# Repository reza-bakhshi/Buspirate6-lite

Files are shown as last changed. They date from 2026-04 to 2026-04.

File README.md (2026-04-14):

# ⚠️ THIS PROJECT IS UNDER ACTIVE DEVELOPMENT AND TESTING  

## DO NOT MANUFACTURE OR USE THE HARDWARE WITHOUT YOUR OWN VERIFICATION

## Overview

This project is currently in progress. Features, hardware design, and functionality may change at any time. Use at your own risk.

---

## Images

### TOP

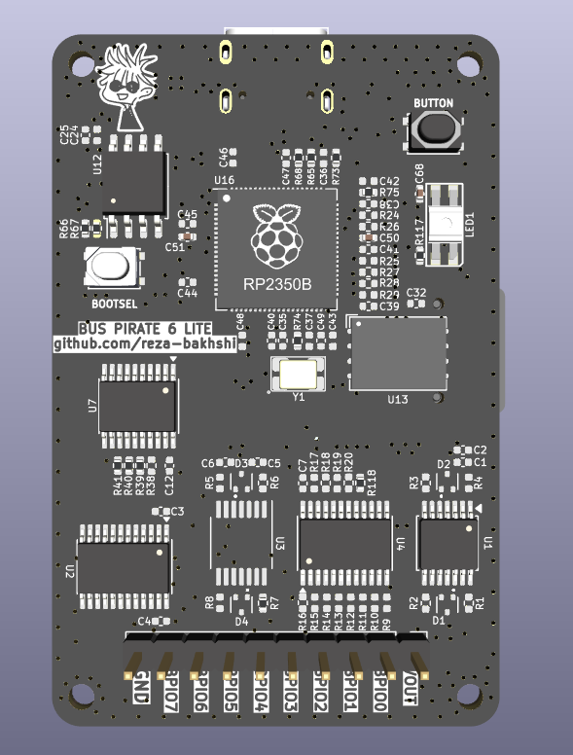
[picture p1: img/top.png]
top


### BOTTOM

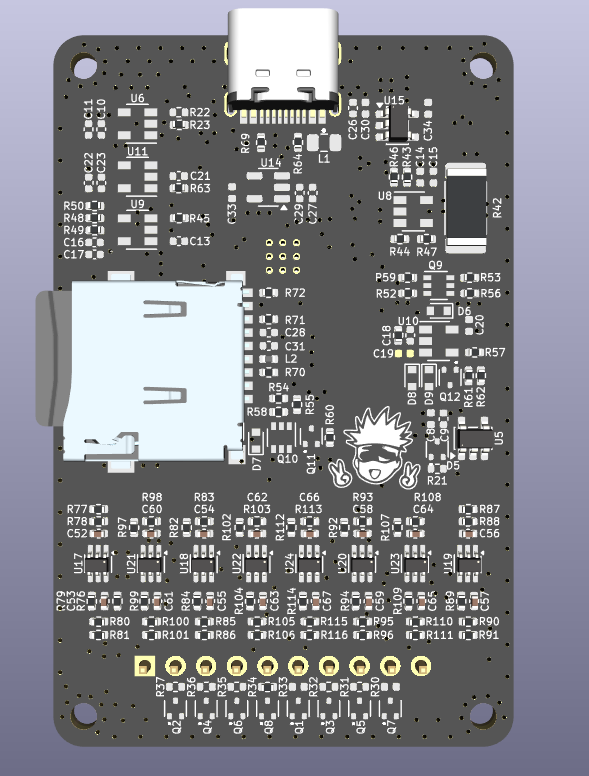
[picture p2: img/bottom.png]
bottom


---

## Notes

- This project is not stable yet.
- Hardware and firmware are still being tested.
- Double-check everything before using or manufacturing.

---

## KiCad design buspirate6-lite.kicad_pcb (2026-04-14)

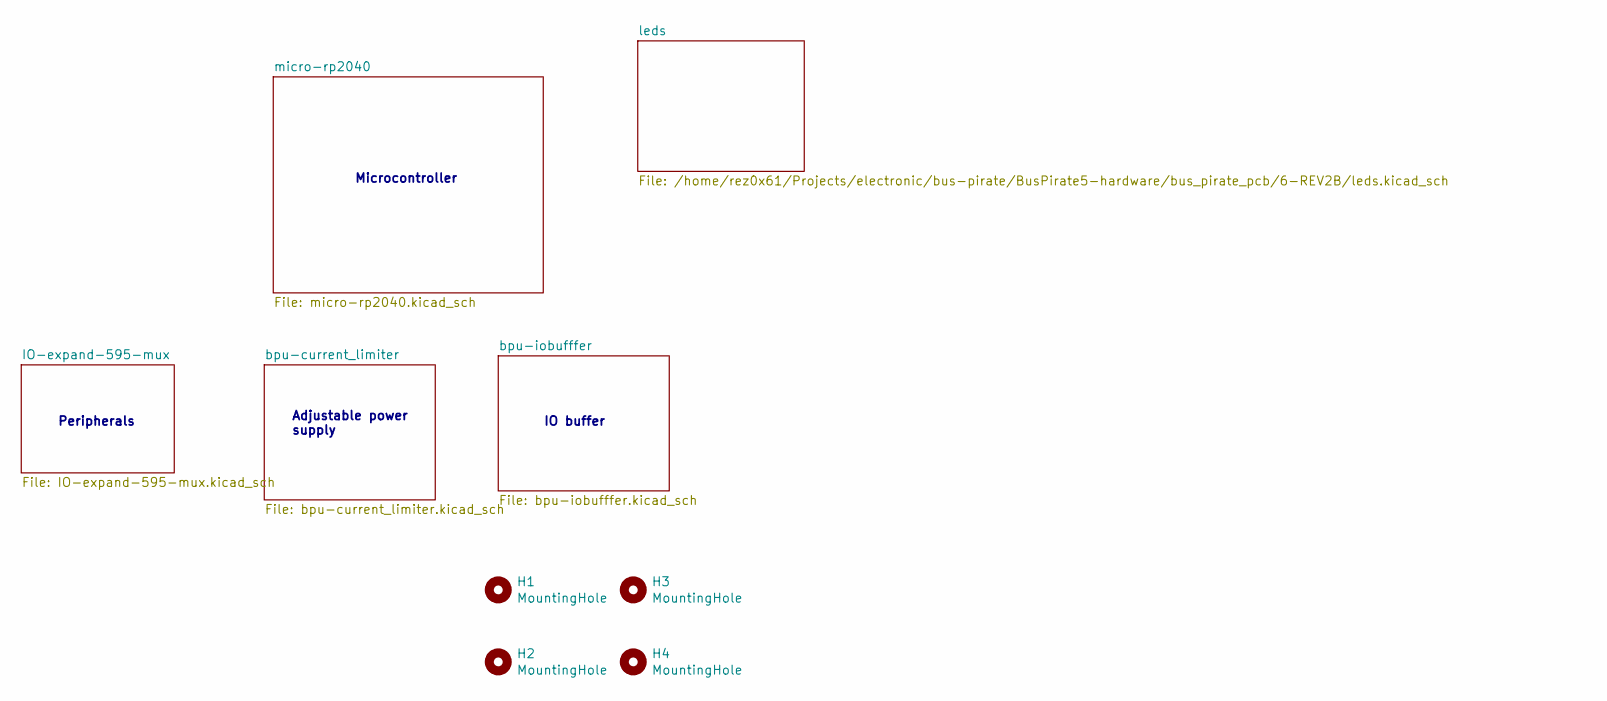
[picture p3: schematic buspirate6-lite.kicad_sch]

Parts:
H1, H2, H3, H4: MountingHole; MountingHole_2.2mm_M2

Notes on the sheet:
Microcontroller
Adjustable power supply
IO buffer
Peripherals

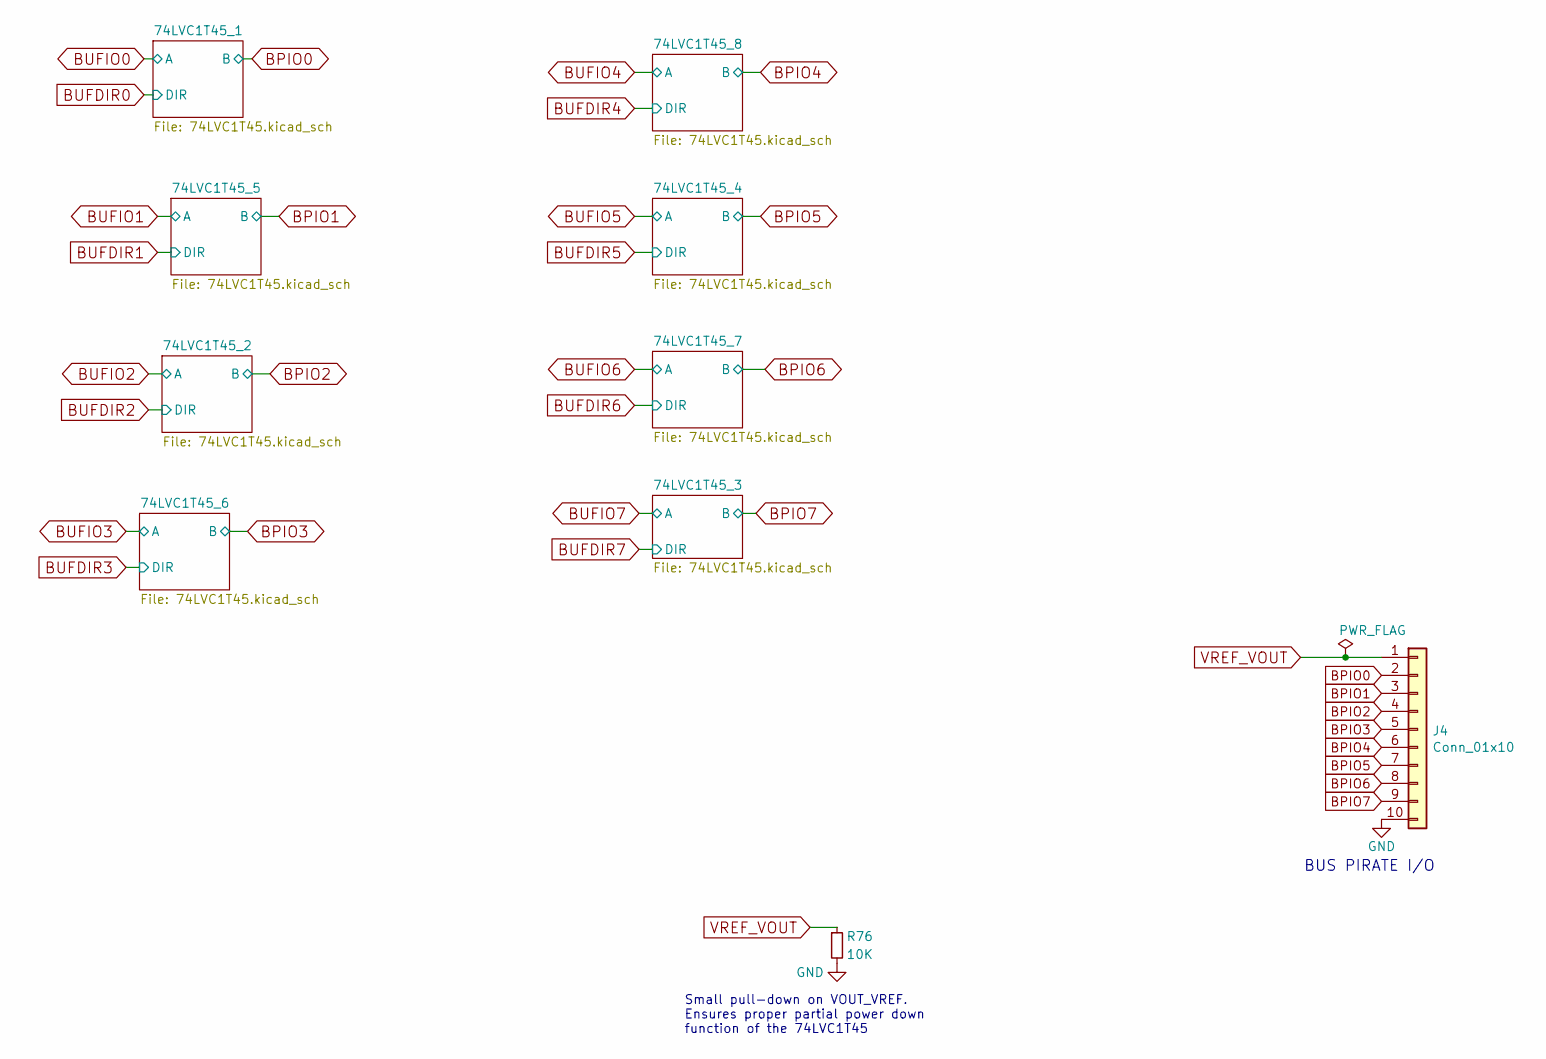
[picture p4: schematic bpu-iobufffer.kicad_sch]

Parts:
J4: Conn_01x10; PinHeader_1x10_P2.54mm_Vertical
R76: 10K; R_0402_1005Metric

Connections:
BPIO0: J4.2; also elsewhere on the board
BPIO1: J4.3; also elsewhere on the board
BPIO2: J4.4; also elsewhere on the board
BPIO3: J4.5; also elsewhere on the board
BPIO4: J4.6; also elsewhere on the board
BPIO5: J4.7; also elsewhere on the board
BPIO6: J4.8; also elsewhere on the board
BPIO7: J4.9; also elsewhere on the board
GND: J4.10, R76.2; also elsewhere on the board
VREF_VOUT: J4.1, R76.1; also elsewhere on the board

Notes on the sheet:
Small pull-down on VOUT_VREF. Ensures proper partial power down function of the 74LVC1T45
BUS PIRATE I/O

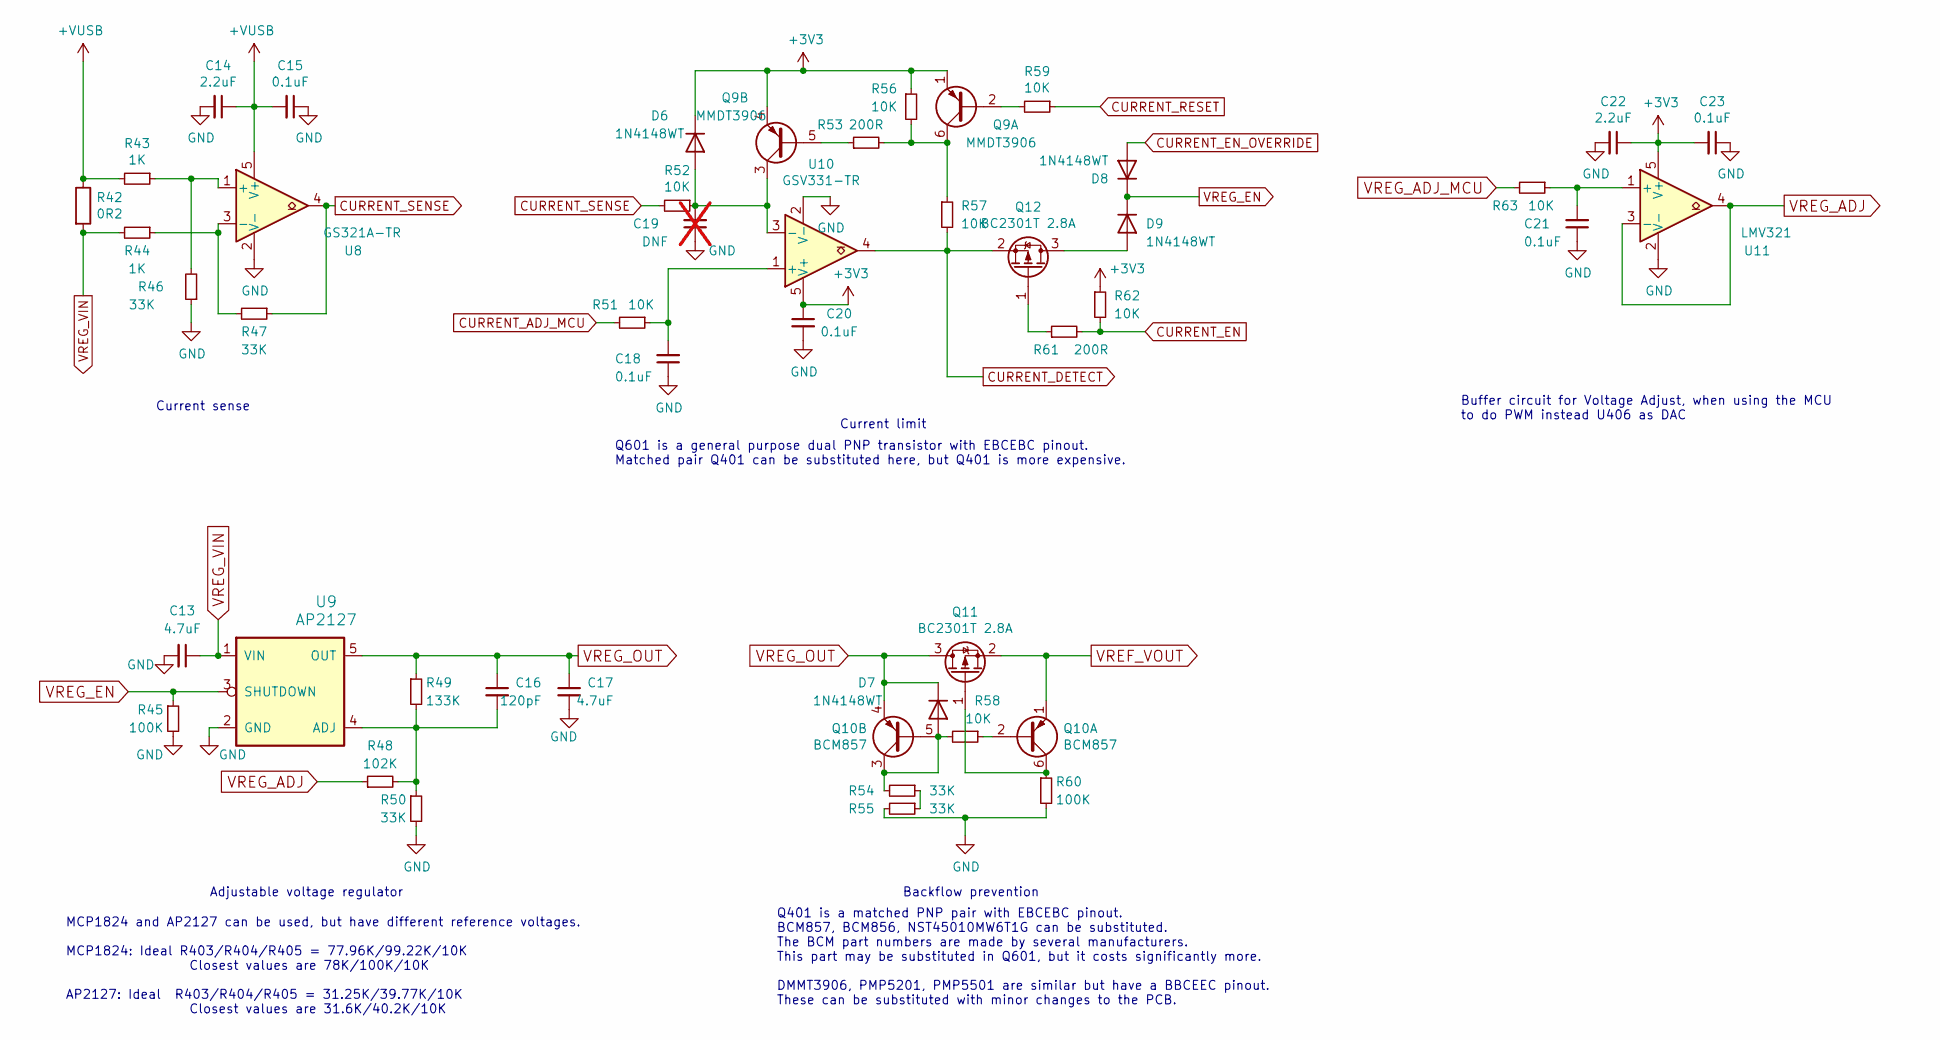
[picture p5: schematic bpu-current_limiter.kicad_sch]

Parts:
C13, C17: 4.7uF; C_0402_1005Metric
C14, C22: 2.2uF; C_0402_1005Metric
C15, C18, C20, C21, C23: 0.1uF; C_0402_1005Metric
C16: 120pF; C_0402_1005Metric
C19: DNF; C_0402_1005Metric; not fitted
D6, D7, D8, D9: 1N4148WT; D_SOD-523
Q9: MMDT3906; SOT-363_SC-70-6
Q10: BCM857; SOT-363_SC-70-6
Q11, Q12: BC2301T 2.8A; SOT-523
R42: 0R2; R_2512_6332Metric_Pad1.40x3.35mm_HandSolder
R43, R44: 1K; R_0402_1005Metric
R45, R60: 100K; R_0402_1005Metric
R46, R47, R50, R54, R55: 33K; R_0402_1005Metric
R48: 102K; R_0402_1005Metric
R49: 133K; R_0402_1005Metric
R51, R52, R56, R57, R58, R59, R62, R63: 10K; R_0402_1005Metric
R53, R61: 200R; R_0402_1005Metric
U8: GS321A-TR; SOT-23-5
U9: AP2127; SOT-23-5
U10: GSV331-TR; SOT-23-5
U11: LMV321; SOT-23-5

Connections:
+3V3: C20.1, C22.1, C23.2, D6.1 (K), Q9.1 (E1), Q9.4 (E2), R56.1, R62.1, U10.5 (V+), U11.5 (V+); also elsewhere on the board
+VUSB: C14.1, C15.2, R42.1, R43.2, U8.5 (V+); also elsewhere on the board
CURRENT_ADJ_MCU: R51.2; also elsewhere on the board
CURRENT_DETECT: Q12.2 (S), R57.2, U10.4; also elsewhere on the board
CURRENT_EN: R61.2, R62.2; also elsewhere on the board
CURRENT_EN_OVERRIDE: D8.2 (A); also elsewhere on the board
CURRENT_RESET: R59.1; also elsewhere on the board
CURRENT_SENSE: R47.1, R52.2, U8.4; also elsewhere on the board
GND: C13.2, C14.2, C15.1, C17.2, C18.1, C19.1, C20.2, C21.1, C22.2, C23.1, R45.2, R46.1, R50.2, R55.2, R60.2, U8.2 (V-), U9.2 (GND), U10.2 (V-), U11.2 (V-); also elsewhere on the board
unnamed: C19.2, D6.2 (A), Q9.3 (C2), R52.1, U10.3 (-)
unnamed: D7.2 (A), Q10.3 (C2), Q10.5 (B2), R54.2, R58.2
unnamed: D9.2 (A), Q12.3 (D)
unnamed: Q9.2 (B1), R59.2
unnamed: Q9.6 (C1), R53.2, R56.2, R57.1
unnamed: Q9.5 (B2), R53.1
unnamed: Q10.2 (B1), R58.1
unnamed: Q10.6 (C1), Q11.1 (G), R60.1
unnamed: Q12.1 (G), R61.1
unnamed: R54.1, R55.1
unnamed: R43.1, R46.2, U8.1 (+)
unnamed: R44.1, R47.2, U8.3 (-)
unnamed: C16.2, R48.2, R49.2, R50.1, U9.4 (ADJ)
unnamed: C18.2, R51.1, U10.1 (+)
unnamed: C21.2, R63.1, U11.1 (+)
VREF_VOUT: Q10.1 (E1), Q11.2 (S); also elsewhere on the board
VREG_ADJ: R48.1, U11.3 (-), U11.4
VREG_ADJ_MCU: R63.2; also elsewhere on the board
VREG_EN: D8.1 (K), D9.1 (K), R45.1, U9.3 (SHUTDOWN)
VREG_OUT: C16.1, C17.1, D7.1 (K), Q10.4 (E2), Q11.3 (D), R49.1, U9.5 (OUT); also elsewhere on the board
VREG_VIN: C13.1, R42.2, R44.2, U9.1 (VIN)

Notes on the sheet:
Adjustable voltage regulator
Buffer circuit for Voltage Adjust, when using the MCU to do PWM instead U406 as DAC
Current sense
Backflow prevention
MCP1824 and AP2127 can be used, but have different reference voltages. MCP1824: Ideal R403/R404/R405 = 77.96K/99.22K/10K Closest values are 78K/100K/10K AP2127: Ideal R403/R404/R405 = 31.25K/39.77K/10K Closest values are 31.6K/40.2K/10K
Current limit
Q401 is a matched PNP pair with EBCEBC pinout. BCM857, BCM856, NST45010MW6T1G can be substituted. The BCM part numbers are made by several manufacturers. This part may be substituted in Q601, but it costs significantly more. DMMT3906, PMP5201, PMP5501 are similar but have a BBCEEC pinout. These can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
Q601 is a general purpose dual PNP transistor with EBCEBC pinout. Matched pair Q401 can be substituted here, but Q401 is more expensive.

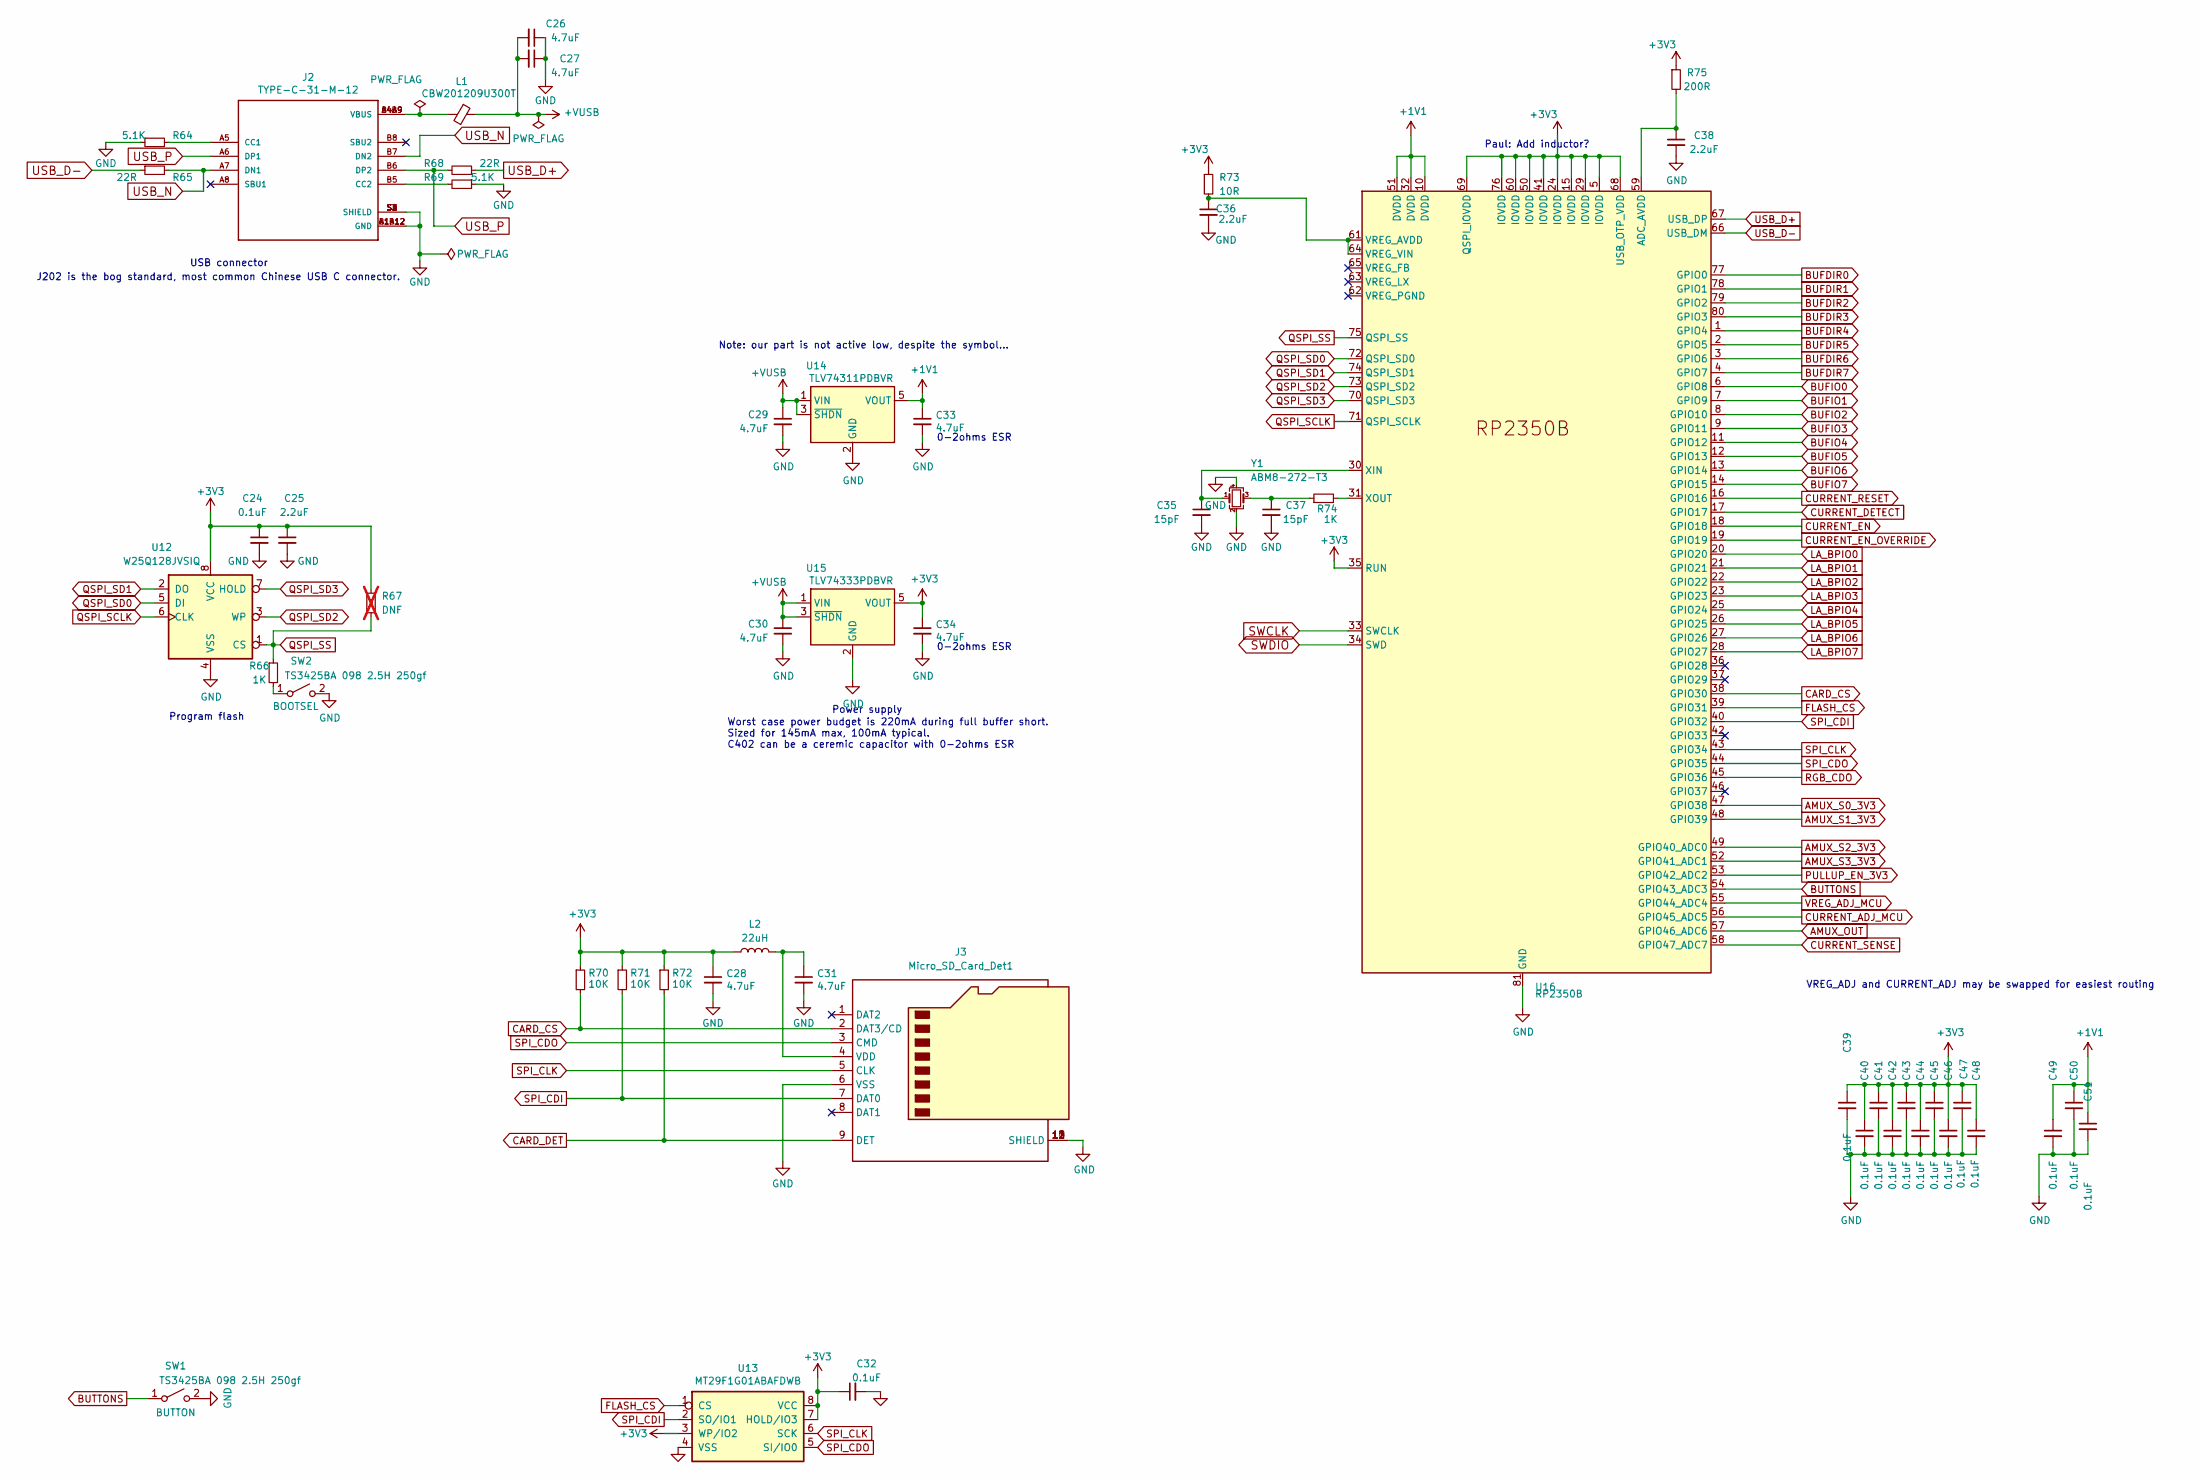
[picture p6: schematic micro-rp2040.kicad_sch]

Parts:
C24, C32, C39, C40, C41, C42, C43, C44, C45, C46, C47, C48, C49, C50, C51: 0.1uF; C_0402_1005Metric
C25, C36, C38: 2.2uF; C_0402_1005Metric
C26, C27, C28, C29, C30, C31, C33, C34: 4.7uF; C_0402_1005Metric
C35, C37: 15pF; C_0402_1005Metric
J2: TYPE-C-31-M-12; HRO_TYPE-C-31-M-12
J3: Micro_SD_Card_Det1; microSD_External_Pin
L1: CBW201209U300T; L_0805_2012Metric
L2: 22uH; L_0402_1005Metric
R64, R69: 5.1K; R_0402_1005Metric
R65, R68: 22R; R_0402_1005Metric
R66, R74: 1K; R_0402_1005Metric
R67: DNF; R_0402_1005Metric; not fitted
R70, R71, R72: 10K; R_0402_1005Metric
R73: 10R; R_0402_1005Metric
R75: 200R; R_0402_1005Metric
SW1, SW2: TS3425BA 098 2.5H 250gf; SW_SPST_PTS810
U12: W25Q128JVSIQ; SOP-8_5.28x5.23mm_P1.27mm
U13: MT29F1G01ABAFDWB; U-PDFN-8
U14: TLV74311PDBVR; SOT-23-5
U15: TLV74333PDBVR; SOT-23-5
U16: RP2350B; qfn80
Y1: ABM8-272-T3; Crystal_SMD_4Pin

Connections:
+1V1: C33.1, C49.1, C50.1, C51.1, U14.5 (VOUT), U16.10 (DVDD), U16.32 (DVDD), U16.51 (DVDD)
+3V3: C24.1, C25.1, C28.1, C32.1, C34.1, C39.1, C40.1, C41.1, C42.1, C43.1, C44.1, C45.1, C46.1, C47.1, C48.1, L2.1, R67.1, R70.1, R71.1, R72.1, R73.1, R75.1, U12.8 (VCC), U13.3 (WP/IO2), U13.7 (HOLD/IO3), U13.8 (VCC), U15.5 (VOUT), U16.5 (IOVDD), U16.15 (IOVDD), U16.24 (IOVDD), U16.29 (IOVDD), U16.35 (RUN), U16.41 (IOVDD), U16.50 (IOVDD), U16.60 (IOVDD), U16.68 (USB_OTP_VDD), U16.69 (QSPI_IOVDD), U16.76 (IOVDD); also elsewhere on the board
+VUSB: C26.2, C27.2, C29.1, C30.1, L1.1, U14.1 (VIN), U14.3 (~SHDN), U15.1 (VIN), U15.3 (~SHDN); also elsewhere on the board
AMUX_OUT: U16.57 (GPIO46_ADC6); also elsewhere on the board
AMUX_S0_3V3: U16.47 (GPIO38); also elsewhere on the board
AMUX_S1_3V3: U16.48 (GPIO39); also elsewhere on the board
AMUX_S2_3V3: U16.49 (GPIO40_ADC0); also elsewhere on the board
AMUX_S3_3V3: U16.52 (GPIO41_ADC1); also elsewhere on the board
BUFDIR0: U16.77 (GPIO0); also elsewhere on the board
BUFDIR1: U16.78 (GPIO1); also elsewhere on the board
BUFDIR2: U16.79 (GPIO2); also elsewhere on the board
BUFDIR3: U16.80 (GPIO3); also elsewhere on the board
BUFDIR4: U16.1 (GPIO4); also elsewhere on the board
BUFDIR5: U16.2 (GPIO5); also elsewhere on the board
BUFDIR6: U16.3 (GPIO6); also elsewhere on the board
BUFDIR7: U16.4 (GPIO7); also elsewhere on the board
BUFIO0: U16.6 (GPIO8); also elsewhere on the board
BUFIO1: U16.7 (GPIO9); also elsewhere on the board
BUFIO2: U16.8 (GPIO10); also elsewhere on the board
BUFIO3: U16.9 (GPIO11); also elsewhere on the board
BUFIO4: U16.11 (GPIO12); also elsewhere on the board
BUFIO5: U16.12 (GPIO13); also elsewhere on the board
BUFIO6: U16.13 (GPIO14); also elsewhere on the board
BUFIO7: U16.14 (GPIO15); also elsewhere on the board
BUTTONS: SW1.1 (A), U16.54 (GPIO43_ADC3)
CARD_CS: J3.2 (DAT3/CD), R70.2, U16.38 (GPIO30)
CARD_DET: J3.9 (DET), R72.2; also elsewhere on the board
CURRENT_ADJ_MCU: U16.56 (GPIO45_ADC5); also elsewhere on the board
CURRENT_DETECT: U16.17 (GPIO17); also elsewhere on the board
CURRENT_EN: U16.18 (GPIO18); also elsewhere on the board
CURRENT_EN_OVERRIDE: U16.19 (GPIO19); also elsewhere on the board
CURRENT_RESET: U16.16 (GPIO16); also elsewhere on the board
CURRENT_SENSE: U16.58 (GPIO47_ADC7); also elsewhere on the board
FLASH_CS: U13.1 (CS), U16.39 (GPIO31)
GND: C24.2, C25.2, C26.1, C27.1, C28.2, C29.2, C30.2, C31.2, C32.2, C33.2, C34.2, C35.2, C36.2, C37.2, C38.2, C39.2, C40.2, C41.2, C42.2, C43.2, C44.2, C45.2, C46.2, C47.2, C48.2, C49.2, C50.2, C51.2, J2.A1B12 (GND), J2.B1A12 (GND), J2.S1 (SHIELD), J2.S2 (SHIELD), J2.S3 (SHIELD), J2.S4 (SHIELD), J3.6 (VSS), J3.10 (SHIELD), J3.11 (SHIELD), J3.12 (SHIELD), J3.13 (SHIELD), R64.1, R69.1, SW1.2 (B), SW2.2 (B), U12.4 (VSS), U13.4 (VSS), U14.2 (GND), U14.4 (GND), U15.2 (GND), U15.4 (GND), U16.81 (GND), Y1.2, Y1.4; also elsewhere on the board
LA_BPIO0: U16.20 (GPIO20); also elsewhere on the board
LA_BPIO1: U16.21 (GPIO21); also elsewhere on the board
LA_BPIO2: U16.22 (GPIO22); also elsewhere on the board
LA_BPIO3: U16.23 (GPIO23); also elsewhere on the board
LA_BPIO4: U16.25 (GPIO24); also elsewhere on the board
LA_BPIO5: U16.26 (GPIO25); also elsewhere on the board
LA_BPIO6: U16.27 (GPIO26); also elsewhere on the board
LA_BPIO7: U16.28 (GPIO27); also elsewhere on the board
unnamed: C37.1, R74.1, Y1.3
unnamed: J2.A5 (CC1), R64.2
unnamed: J2.B5 (CC2), R69.2
unnamed: J2.A4B9 (VBUS), J2.B4A9 (VBUS), L1.2
unnamed: C31.1, J3.4 (VDD), L2.2
unnamed: R66.2, SW2.1 (A)
unnamed: C38.1, R75.2, U16.59 (ADC_AVDD)
unnamed: C36.1, R73.2, U16.61 (VREG_AVDD), U16.64 (VREG_VIN)
unnamed: C35.1, U16.30 (XIN), Y1.1
unnamed: R74.2, U16.31 (XOUT)
PULLUP_EN_3V3: U16.53 (GPIO42_ADC2); also elsewhere on the board
QSPI_SCLK: U12.6 (CLK), U16.71 (QSPI_SCLK)
QSPI_SD0: U12.5 (DI), U16.72 (QSPI_SD0)
QSPI_SD1: U12.2 (DO), U16.74 (QSPI_SD1)
QSPI_SD2: U12.3 (WP), U16.73 (QSPI_SD2)
QSPI_SD3: U12.7 (HOLD), U16.70 (QSPI_SD3)
QSPI_SS: R66.1, R67.2, U12.1 (CS), U16.75 (QSPI_SS)
RGB_CDO: U16.45 (GPIO36); also elsewhere on the board
SPI_CDI: J3.7 (DAT0), R71.2, U13.2 (SO/IO1), U16.40 (GPIO32)
SPI_CDO: J3.3 (CMD), U13.5 (SI/IO0), U16.44 (GPIO35)
SPI_CLK: J3.5 (CLK), U13.6 (SCK), U16.43 (GPIO34)
SWCLK: U16.33 (SWCLK)
SWDIO: U16.34 (SWD)
USB_D+: R68.1, U16.67 (USB_DP)
USB_D-: R65.1, U16.66 (USB_DM)
USB_N: J2.A7 (DN1), J2.B7 (DN2), R65.2
USB_P: J2.A6 (DP1), J2.B6 (DP2), R68.2
VREG_ADJ_MCU: U16.55 (GPIO44_ADC4); also elsewhere on the board

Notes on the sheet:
Note: our part is not active low, despite the symbol...
USB connector
Power supply
J202 is the bog standard, most common Chinese USB C connector.
Program flash
Worst case power budget is 220mA during full buffer short. Sized for 145mA max, 100mA typical. C402 can be a ceremic capacitor with 0-2ohms ESR
Paul: Add inductor?
VREG_ADJ and CURRENT_ADJ may be swapped for easiest routing
0-2ohms ESR

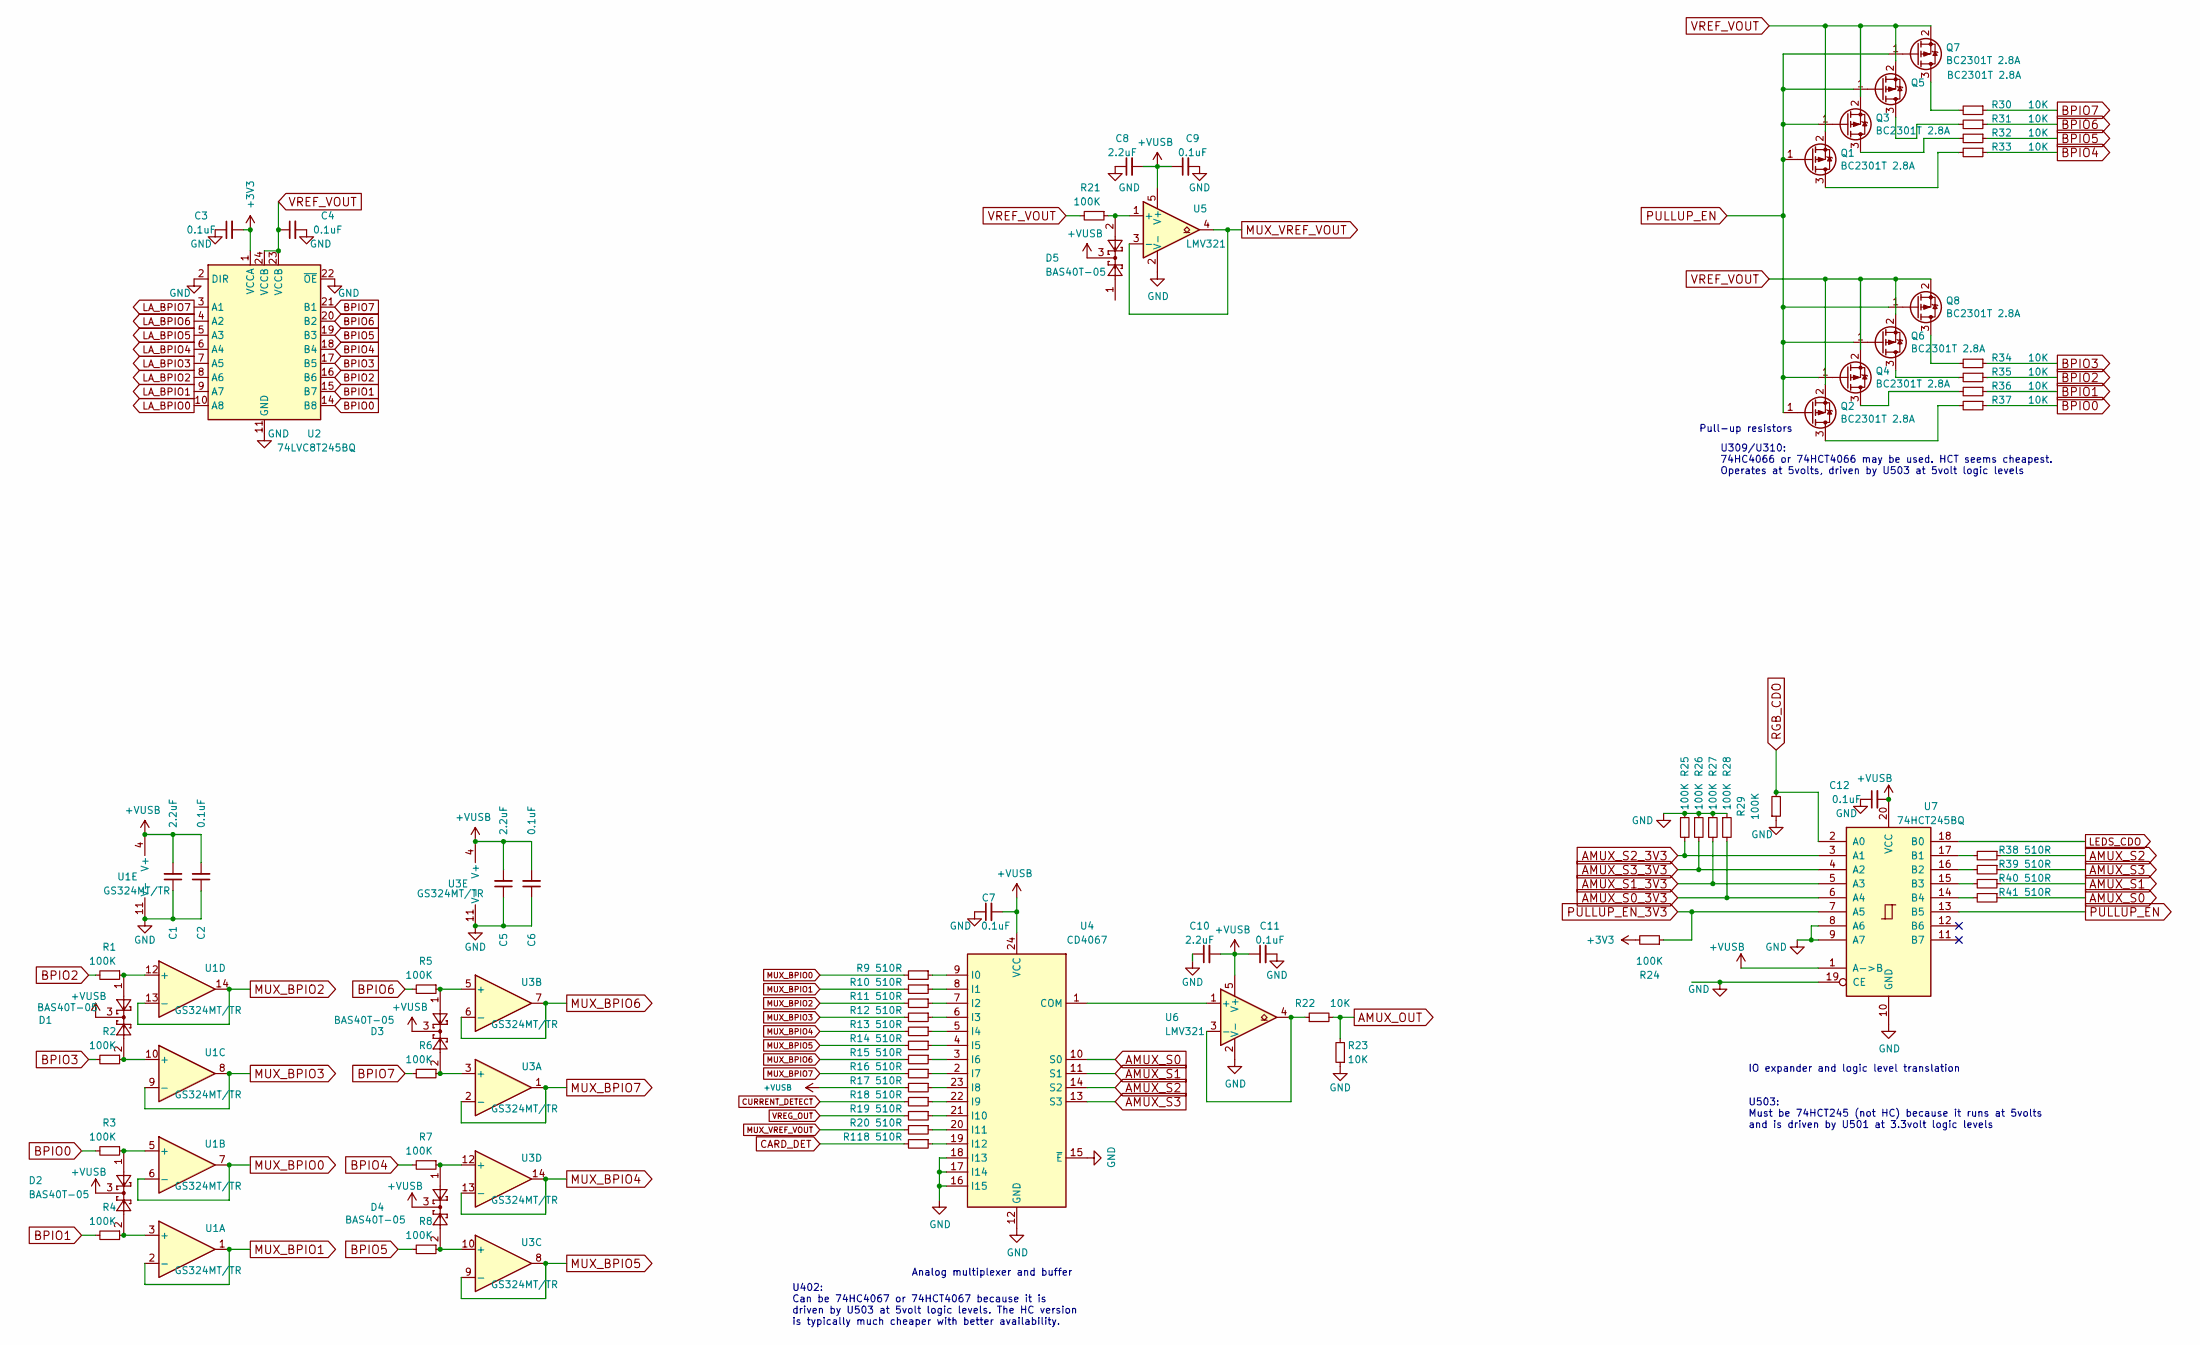
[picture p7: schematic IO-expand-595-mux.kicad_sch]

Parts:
C1, C5, C8, C10: 2.2uF; C_0402_1005Metric
C2, C3, C4, C6, C7, C9, C11, C12: 0.1uF; C_0402_1005Metric
D1, D2, D3, D4, D5: BAS40T-05; SOT-523
Q1, Q2, Q3, Q4, Q5, Q6, Q7, Q8: BC2301T 2.8A; SOT-523
R1, R2, R3, R4, R5, R6, R7, R8, R21, R24, R25, R26, R27, R28, R29: 100K; R_0402_1005Metric
R9, R10, R11, R12, R13, R14, R15, R16, R17, R18, R19, R20, R38, R39, R40, R41, R118: 510R; R_0402_1005Metric
R22, R23, R30, R31, R32, R33, R34, R35, R36, R37: 10K; R_0402_1005Metric
U1, U3: GS324MT/TR; TSSOP-14_4.4x5mm_P0.65mm
U2: 74LVC8T245BQ; TSSOP-24_4.4x7.8mm_P0.65mm
U4: CD4067; TSSOP-24_4.4x7.8mm_P0.65mm
U5, U6: LMV321; SOT-23-5
U7: 74HCT245BQ; TSSOP-20_4.4x6.5mm_P0.65mm

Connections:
+3V3: C3.2, R24.2, U2.1 (VCCA); also elsewhere on the board
+VUSB: C1.2, C2.2, C5.2, C6.2, C7.2, C8.2, C9.1, C10.2, C11.1, C12.2, D1.3, D2.3, D3.3, D4.3, D5.3, R17.2, U1.4 (V+), U3.4 (V+), U4.24 (VCC), U5.5 (V+), U6.5 (V+), U7.1 (A->B), U7.20 (VCC); also elsewhere on the board
AMUX_OUT: R22.2, R23.2; also elsewhere on the board
AMUX_S0: R41.1, U4.10 (S0)
AMUX_S0_3V3: R28.2, U7.6 (A4); also elsewhere on the board
AMUX_S1: R40.1, U4.11 (S1)
AMUX_S1_3V3: R27.2, U7.5 (A3); also elsewhere on the board
AMUX_S2: R38.1, U4.14 (S2)
AMUX_S2_3V3: R25.2, U7.3 (A1); also elsewhere on the board
AMUX_S3: R39.1, U4.13 (S3)
AMUX_S3_3V3: R26.2, U7.4 (A2); also elsewhere on the board
BPIO0: R3.2, R37.1, U2.14 (B8); also elsewhere on the board
BPIO1: R4.2, R36.1, U2.15 (B7); also elsewhere on the board
BPIO2: R1.2, R35.1, U2.16 (B6); also elsewhere on the board
BPIO3: R2.2, R34.1, U2.17 (B5); also elsewhere on the board
BPIO4: R7.2, R33.1, U2.18 (B4); also elsewhere on the board
BPIO5: R8.2, R32.1, U2.19 (B3); also elsewhere on the board
BPIO6: R5.2, R31.1, U2.20 (B2); also elsewhere on the board
BPIO7: R6.2, R30.1, U2.21 (B1); also elsewhere on the board
CARD_DET: R118.2; also elsewhere on the board
CURRENT_DETECT: R18.2; also elsewhere on the board
GND: C1.1, C2.1, C3.1, C4.2, C5.1, C6.1, C7.1, C8.1, C9.2, C10.1, C11.2, C12.1, R23.1, R25.1, R26.1, R27.1, R28.1, R29.1, U1.11 (V-), U2.2 (DIR), U2.11 (GND), U2.12 (GND), U2.13 (GND), U2.22 (~OE), U3.11 (V-), U4.12 (GND), U4.15 (~E), U4.16 (I15), U4.17 (I14), U4.18 (I13), U5.2 (V-), U6.2 (V-), U7.8 (A6), U7.9 (A7), U7.10 (GND), U7.19 (CE); also elsewhere on the board
LA_BPIO0: U2.10 (A8); also elsewhere on the board
LA_BPIO1: U2.9 (A7); also elsewhere on the board
LA_BPIO2: U2.8 (A6); also elsewhere on the board
LA_BPIO3: U2.7 (A5); also elsewhere on the board
LA_BPIO4: U2.6 (A4); also elsewhere on the board
LA_BPIO5: U2.5 (A3); also elsewhere on the board
LA_BPIO6: U2.4 (A2); also elsewhere on the board
LA_BPIO7: U2.3 (A1); also elsewhere on the board
LEDS_CDO: U7.18 (B0); also elsewhere on the board
MUX_BPIO0: R9.2, U1.6 (-), U1.7
MUX_BPIO1: R10.2, U1.1, U1.2 (-)
MUX_BPIO2: R11.2, U1.13 (-), U1.14
MUX_BPIO3: R12.2, U1.8, U1.9 (-)
MUX_BPIO4: R13.2, U3.13 (-), U3.14
MUX_BPIO5: R14.2, U3.8, U3.9 (-)
MUX_BPIO6: R15.2, U3.6 (-), U3.7
MUX_BPIO7: R16.2, U3.1, U3.2 (-)
MUX_VREF_VOUT: R20.2, U5.3 (-), U5.4
unnamed: Q1.3 (D), R33.2
unnamed: Q2.3 (D), R37.2
unnamed: Q3.3 (D), R32.2
unnamed: Q4.3 (D), R36.2
unnamed: Q5.3 (D), R31.2
unnamed: Q6.3 (D), R35.2
unnamed: Q7.3 (D), R30.2
unnamed: Q8.3 (D), R34.2
unnamed: D2.2, R4.1, U1.3 (+)
unnamed: D2.1, R3.1, U1.5 (+)
unnamed: D1.2, R2.1, U1.10 (+)
unnamed: D1.1, R1.1, U1.12 (+)
unnamed: D3.2, R6.1, U3.3 (+)
unnamed: D3.1, R5.1, U3.5 (+)
unnamed: D4.2, R8.1, U3.10 (+)
unnamed: D4.1, R7.1, U3.12 (+)
unnamed: U4.1 (COM), U6.1 (+)
unnamed: R9.1, U4.9 (I0)
unnamed: R10.1, U4.8 (I1)
unnamed: R11.1, U4.7 (I2)
unnamed: R12.1, U4.6 (I3)
unnamed: R13.1, U4.5 (I4)
unnamed: R14.1, U4.4 (I5)
unnamed: R15.1, U4.3 (I6)
unnamed: R16.1, U4.2 (I7)
unnamed: R17.1, U4.23 (I8)
unnamed: R18.1, U4.22 (I9)
unnamed: R19.1, U4.21 (I10)
unnamed: R20.1, U4.20 (I11)
unnamed: R118.1, U4.19 (I12)
unnamed: D5.2, R21.1, U5.1 (+)
unnamed: R22.1, U6.3 (-), U6.4
unnamed: R38.2, U7.17 (B1)
unnamed: R39.2, U7.16 (B2)
unnamed: R40.2, U7.15 (B3)
unnamed: R41.2, U7.14 (B4)
PULLUP_EN: Q1.1 (G), Q2.1 (G), Q3.1 (G), Q4.1 (G), Q5.1 (G), Q6.1 (G), Q7.1 (G), Q8.1 (G), U7.13 (B5)
PULLUP_EN_3V3: R24.1, U7.7 (A5); also elsewhere on the board
RGB_CDO: R29.2, U7.2 (A0); also elsewhere on the board
VREF_VOUT: C4.1, Q1.2 (S), Q2.2 (S), Q3.2 (S), Q4.2 (S), Q5.2 (S), Q6.2 (S), Q7.2 (S), Q8.2 (S), R21.2, U2.23 (VCCB), U2.24 (VCCB); also elsewhere on the board
VREG_OUT: R19.2; also elsewhere on the board

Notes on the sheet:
IO expander and logic level translation
Analog multiplexer and buffer
U402: Can be 74HC4067 or 74HCT4067 because it is driven by U503 at 5volt logic levels. The HC version is typically much cheaper with better availability.
U503: Must be 74HCT245 (not HC) because it runs at 5volts and is driven by U501 at 3.3volt logic levels
U309/U310: 74HC4066 or 74HCT4066 may be used. HCT seems cheapest. Operates at 5volts, driven by U503 at 5volt logic levels
Pull-up resistors

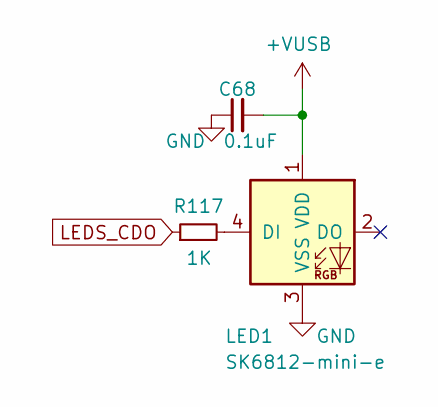
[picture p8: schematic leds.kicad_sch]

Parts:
C68: 0.1uF; C_0402_1005Metric
LED1: SK6812-mini-e
R117: 1K; R_0402_1005Metric

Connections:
+VUSB: C68.2, LED1.1 (VDD); also elsewhere on the board
GND: C68.1, LED1.3 (VSS); also elsewhere on the board
LEDS_CDO: R117.1; also elsewhere on the board
unnamed: LED1.4 (DI), R117.2

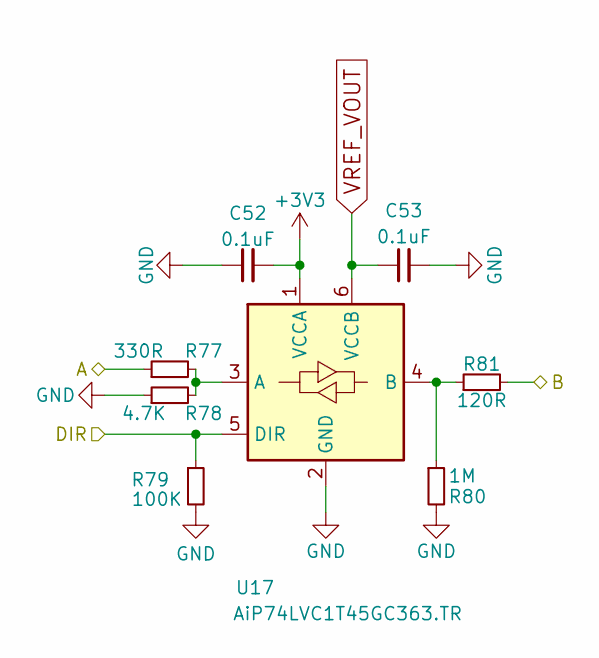
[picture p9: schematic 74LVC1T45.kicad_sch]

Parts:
C52, C53: 0.1uF; C_0402_1005Metric
R77: 330R; R_0402_1005Metric
R78: 4.7K; R_0402_1005Metric
R79: 100K; R_0402_1005Metric
R80: 1M; R_0402_1005Metric
R81: 120R; R_0402_1005Metric
U17: AiP74LVC1T45GC363.TR; SOT-363_SC-70-6

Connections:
+3V3: C52.2, U17.1 (VCCA); also elsewhere on the board
BPIO0: R81.2; also elsewhere on the board
BUFDIR0: R79.1, U17.5 (DIR); also elsewhere on the board
BUFIO0: R77.1; also elsewhere on the board
GND: C52.1, C53.2, R78.1, R79.2, R80.2, U17.2 (GND); also elsewhere on the board
unnamed: R77.2, R78.2, U17.3 (A)
unnamed: R80.1, R81.1, U17.4 (B)
VREF_VOUT: C53.1, U17.6 (VCCB); also elsewhere on the board

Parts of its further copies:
C54, C55, C56, C57, C58, C59, C60, C61, C62, C63, C64, C65, C66, C67: 0.1uF; C_0402_1005Metric
R82, R87, R92, R97, R102, R107, R112: 330R; R_0402_1005Metric
R83, R88, R93, R98, R103, R108, R113: 4.7K; R_0402_1005Metric
R84, R89, R94, R99, R104, R109, R114: 100K; R_0402_1005Metric
R85, R90, R95, R100, R105, R110, R115: 1M; R_0402_1005Metric
R86, R91, R96, R101, R106, R111, R116: 120R; R_0402_1005Metric
U18, U19, U20, U21, U22, U23, U24: AiP74LVC1T45GC363.TR; SOT-363_SC-70-6

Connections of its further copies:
+3V3: C54.2, C56.2, C58.2, C60.2, C62.2, C64.2, C66.2, U18.1 (VCCA), U19.1 (VCCA), U20.1 (VCCA), U21.1 (VCCA), U22.1 (VCCA), U23.1 (VCCA), U24.1 (VCCA); also elsewhere on the board
BPIO1: R101.2; also elsewhere on the board
BPIO2: R86.2; also elsewhere on the board
BPIO3: R106.2; also elsewhere on the board
BPIO4: R116.2; also elsewhere on the board
BPIO5: R96.2; also elsewhere on the board
BPIO6: R111.2; also elsewhere on the board
BPIO7: R91.2; also elsewhere on the board
BUFDIR1: R99.1, U21.5 (DIR); also elsewhere on the board
BUFDIR2: R84.1, U18.5 (DIR); also elsewhere on the board
BUFDIR3: R104.1, U22.5 (DIR); also elsewhere on the board
BUFDIR4: R114.1, U24.5 (DIR); also elsewhere on the board
BUFDIR5: R94.1, U20.5 (DIR); also elsewhere on the board
BUFDIR6: R109.1, U23.5 (DIR); also elsewhere on the board
BUFDIR7: R89.1, U19.5 (DIR); also elsewhere on the board
BUFIO1: R97.1; also elsewhere on the board
BUFIO2: R82.1; also elsewhere on the board
BUFIO3: R102.1; also elsewhere on the board
BUFIO4: R112.1; also elsewhere on the board
BUFIO5: R92.1; also elsewhere on the board
BUFIO6: R107.1; also elsewhere on the board
BUFIO7: R87.1; also elsewhere on the board
GND: C54.1, C55.2, C56.1, C57.2, C58.1, C59.2, C60.1, C61.2, C62.1, C63.2, C64.1, C65.2, C66.1, C67.2, R83.1, R84.2, R85.2, R88.1, R89.2, R90.2, R93.1, R94.2, R95.2, R98.1, R99.2, R100.2, R103.1, R104.2, R105.2, R108.1, R109.2, R110.2, R113.1, R114.2, R115.2, U18.2 (GND), U19.2 (GND), U20.2 (GND), U21.2 (GND), U22.2 (GND), U23.2 (GND), U24.2 (GND); also elsewhere on the board
unnamed: R82.2, R83.2, U18.3 (A)
unnamed: R85.1, R86.1, U18.4 (B)
unnamed: R87.2, R88.2, U19.3 (A)
unnamed: R90.1, R91.1, U19.4 (B)
unnamed: R92.2, R93.2, U20.3 (A)
unnamed: R95.1, R96.1, U20.4 (B)
unnamed: R97.2, R98.2, U21.3 (A)
unnamed: R100.1, R101.1, U21.4 (B)
unnamed: R102.2, R103.2, U22.3 (A)
unnamed: R105.1, R106.1, U22.4 (B)
unnamed: R107.2, R108.2, U23.3 (A)
unnamed: R110.1, R111.1, U23.4 (B)
unnamed: R112.2, R113.2, U24.3 (A)
unnamed: R115.1, R116.1, U24.4 (B)
VREF_VOUT: C55.1, C57.1, C59.1, C61.1, C63.1, C65.1, C67.1, U18.6 (VCCB), U19.6 (VCCB), U20.6 (VCCB), U21.6 (VCCB), U22.6 (VCCB), U23.6 (VCCB), U24.6 (VCCB); also elsewhere on the board

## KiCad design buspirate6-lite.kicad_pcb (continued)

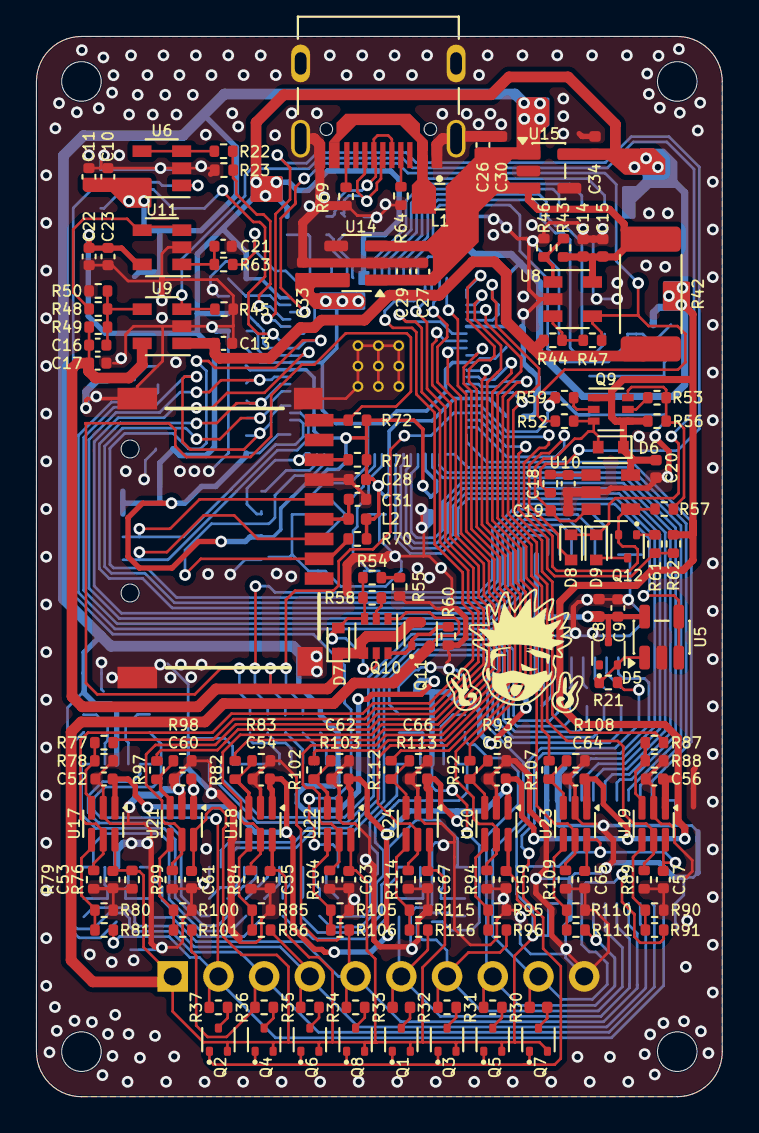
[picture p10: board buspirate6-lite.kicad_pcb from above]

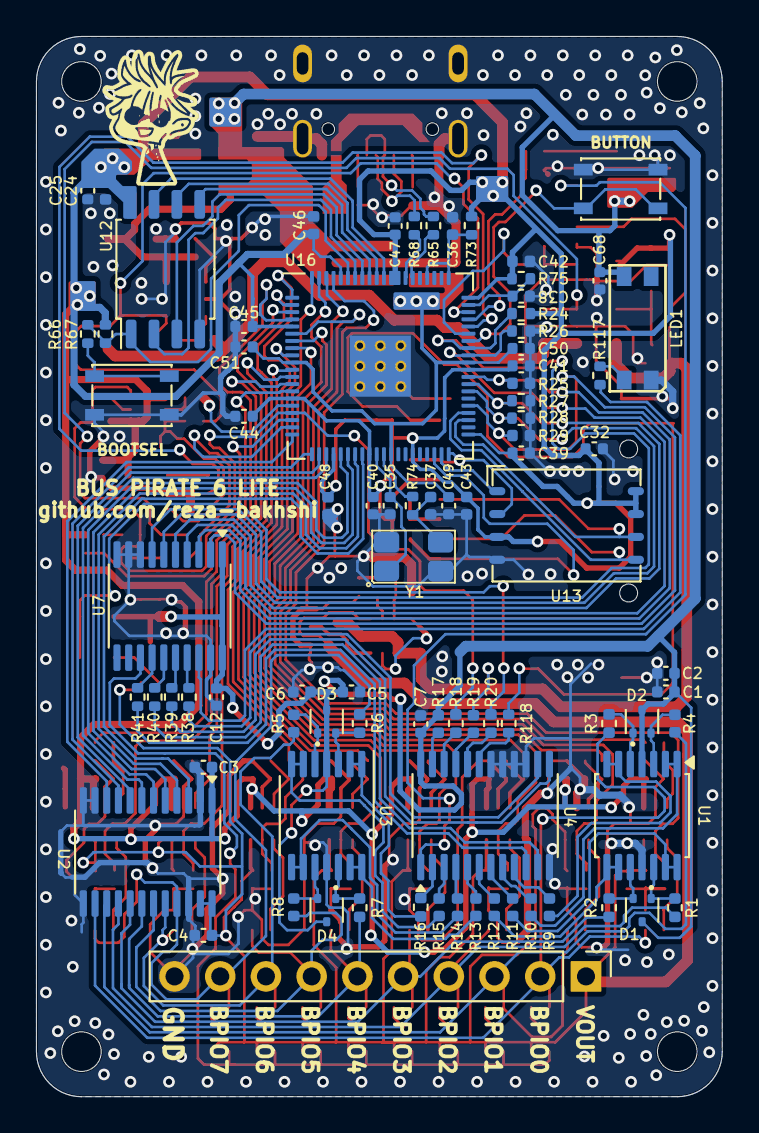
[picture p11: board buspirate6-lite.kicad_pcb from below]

Board: 2 copper layers, 38.1 x 58.9 mm, 244 parts (87 on the bottom side), 165 nets.
